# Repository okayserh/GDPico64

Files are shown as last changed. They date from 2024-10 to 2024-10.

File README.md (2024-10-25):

# GDPico64
Raspberry pico based graphics card to emulate an 80s EF9365 based graphics card to be used in conjunction with a modular 8 bit Z80 based computer system.

# Background
In the mid/late 80s, german public television broadcasted a series of 26 episodes of a stepwise introduction to microcomputer technology. It started with the usual stuff like binary logic, memory and the purpose of a central processing unit. Parallel to the explanations the series worked on building a modular 8 bit microcomputer, which was based on an 8 bit bus system. While the basic system used the Z80 CPU, it was possible to extend the system to an 68008 CPU board and with some tricks even to an 68020 CPU.
A full set of information and the required software is available on the following website (most of it is in german language):
www.ndr-nkc.de
In its modular setup it is conceptually very similar to the RC2014* project.

# Project
One cornerstone of the modular computer system was the graphics card named GDP64, where the 64 stands for 64kB of dedicated graphics memory, which offered 4 separate pages of 512x256 monochrome pixels (rather hi-res for that time!). The GDP64 was designed around the EF9365 graphics chip, which seems to have been one of the first graphics chips to offer a hardware implementation of graphics primitives like lines or characters. Since the chip has a MAME (www.mamedev.org) implementation, it seems to have found some use outside of this modular computer project but overall it is rather exotic. While the line drawing performance was quite impressive for its time with up to 1 Mio. Pixels/s, it lacked some features like scrolling or dedicated text modes.

This project uses the capabilities of the RP2040 to create a graphics output to support halfway modern displays (i.e. it produces an analog VGA signal where the current preferred resolution is 1920x1080@60Hz). Furthermore, the RP2040 provides a parallel interface to enable use of the GDPico64 in the same environment as the original.

As some GPIOs were free after having 8 Bit Color VGA output and the parallel bus, the board offers a PS/2 interface to connect a keyboard (this emulates the old KEY group). As an additional means of interfacing with the Z80 system, the Pico's stdio functionaliy (i.e. UART via USB) can also be used as keyboard input.

# Installation
The project assumes that the standard Pico SDK has been setup as documented in the official docs.

First the repository needs to be cloned into a separate directory:
```
git clone https://github.com/okayserh/GDPico64
```

Submodules are used to provide the FreeRTOS functions. These need to be cloned by:
```
git submodule update --init
```

For compiling the code a build directory needs to be setup with subsequent use of the CMake system
```
mkdir build
cd build
cmake ..
```

Building is than just
```
make
```

Installation on the Pico board follows the standard procedure. I.e. the .uf2 file created by the
build process is copied onto the drive presented by the Pico board.

# Usage
For the beginning, it is suggested to have a serial interface via USB. Once the initialization is completed, the monitor switches to "terminal" mode. In "terminal mode", the input received via the stdio serial interface is forwarded as key press to the Z80 system. Thus, the host keyboard can be used as input for the Z80 system. Pressing the ESC key of the host system, the software switches to "monitor mode". In monitor mode the following functions are available:

* X XModem receive
* S XModem send
* D Dump XModem buffer
* T Terminal mode
* I Dump IO buffer
* C Reset CAS bufptr
* R Reset Z80

The three functions XModem receive XModem send and Reset CAS bufptr are linked to the emulation of the original cassette interface (CAS). This interface uses a 6850 UART to convert data streams into recordable audio. The emulation uses a 4k buffer in RAM as a substitute for the cassette. The buffer can be filled from the host computer or the Z80. When the buffer has been filled via XModem, the pointer can be reset (via C) and the Z80 can read the data via the emulated 6850 interface. This allows the transmission of programs into the Z80 environment via XModem. For the opposite direction, the pointer into the buffer should be reset and the transmission from the Z80 be started. When the buffer has been filled, the XModem buffer can be send to the host computer via XModem.

With the "Dump XModel buffer" function, the current content of the cassette buffer can be displayed through the serial interface via USB.

As a debugging function, "Dump IO buffer" outputs all 256 IO registers that are used internally to emulate the different IO devices.

Finally, the "Reset Z80" function sends a reset signal via the Z80 bus and reinitializes the PIO handling the parallel bus.

# Remarks and TODOs
* As this is a weekend project, the code is not yet very nice from a software engineering or code quality perspective. Time allowing, the code quality will be improved and maybe also new features will be added.
* For many of the functions that are implemented in the code, I've been looking for sources to get some inspiration (DMA based LUT mapping, parallel port implementation). While there are some codes, I still think that the code may provide some insights into how those tasks could be done if these things should become part of another project.
* FreeRTOS was added in a later stage of the project as multiple things need to be monitored simultaneously and the initial simple scheduler became overly complex. Usage of FreeRTOS may not always be as it should be. But for the time being the code seems to work.
* The monitor is rather simple and only accessible from the USB serial interface. A possible extension would be to use the graphics output to provide a stand-alone monitor program that can be used to confgure the system
* Another extension would be to use the 8 bit color output to provide a color capable graphics interface. A simple concept would use the 4 pages as 4 bits encoding the color through the lookup table.
* Generally it is also conceivable to complete change the graphics interface into something more like an 80s homecomputer graphics.
* Addition of the floppy controller to enable the use of CP/M.

# Trademarks
    "RC2014" is a registered trademark of RFC2795 Ltd.
    Other names and brands may be claimed as the property of others.

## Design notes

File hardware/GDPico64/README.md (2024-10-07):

# GDPico64, Hardware
Raspberry pico based graphics card to emulate an 80s EF9365 based graphics card to be used in conjunction with a modular 8 bit Z80 based computer system.

# Layout and functions
Since my background is more on the software side, this is the first PCB I've developed. While it works in my setup, it may lack some features professional PCB designers or electrical engineers would add.

It uses 74245 chips to translate the Z80 bus signals into 3.3v signals that are compatible to the Pico GPIO pins. In order to save GPIOs on the Pico, the address and data part of the bus is multiplixed by using two 74245 chips. For outputting data signals to the Z80 bus, the 74245 chips are used as well. However, for the controlling the RESET and the WAIT signal an 5V inverter is used. While the 74245 worked for those signals as well in my breadboard development setup, there seems to be a risk that the 74245 is used out of spec in this setup when pull-up resitors drive the signals to 5V.

The VGA output is a simple resistor network inspired by the PICO VGA library.

Known shortcomings:
* No guarantee to do anything useful and leave other components to be used in conjuntion with this PCB undamaged! Use at your own risk!
* No protection against powering the Pico via the parallel bus and the USB port.
* As of now, only tested in a configuration where the whole system is powered through the USB port of the Pico.

# Release Notes
* Version 0.1:
  * Initial version

# Licensing

The hardware design itself, including schematic and PCB layout design files are licensed under the strongly-reciprocal variant of [CERN Open Hardware Licence version 2](license-cern_ohl_s_v2.txt).

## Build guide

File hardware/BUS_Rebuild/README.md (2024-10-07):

# BUS "Rebuild"
The BUS group was at the heart of the modular computer system. It provided a bus for 6 PCBs that usually included the CPU, some memory cards and some IO respectively Graphics cards.

Since the original PCBs are "unobtainium", I've spend an evening redesigning the original BUS backplane. I've made a few minor modifications to the original layout.

# Licensing

The hardware design itself, including schematic and PCB layout design files are licensed under the strongly-reciprocal variant of [CERN Open Hardware Licence version 2](license-cern_ohl_s_v2.txt).

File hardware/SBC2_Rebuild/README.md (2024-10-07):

# SBC2 "Rebuild"
The SBC2 was a card that included the Z80 CPU, 8k of EPROM and 4k of RAM on a single PCB. The EPROM was mapped to 0x0000-0x2000, while the RAM was located from 0x8000 to 0x9000. In order to have a complete system on the PCB, an oscillator circuit and the reset logic were also implemented on the board.

It is important to note, that this board was merely enough to use the basic program ("grundprogramm"), which could be considered a simple monitor with extensions to enter simple machine code programs and to write those programs to the cassette interface. For user interested in getting more from the modular concept, separate cards with distinct CPUs and Memories were offered. By using these cards, the system could be extended to 1MB of memory with some bank logic. In those configurations it was also possible to use the system together with CP/M.

Since my original SBC2 board was messed up with wrong solders, I decided to redraw the SBC2 with KiCad and order replacements from a PCB shop. The result can be found in this folder.

# Remarks:
The required memory types 2732 and 6116 are hard to come by today. With hindsight bias, it was not such a good idea to spend time to replicate this design. In my current working setup, the card is only populated with a single 6116, while the sockets are filled with wires to forward the address lines that are not provided to the bus in the original design. Also the reset logic is left unpopulated as the reset must be provided by the GDPico64 in order to have the parallel bus set up properly. Henc,e, in my working setup it is mostly used ad clock generator and holder for the Z80 CPU.
Another point which seems not quite up to date is the dimensioning of the pull-up resistors. Those are 1k resistors, which to me seem rather strong by current CMOS standards.
The logic for the clock generation works, but the signal is not very good. Using an off the shelve oscillator might have been a better option for the redesign.

# Licensing
The copyright of the original PCB design is by Rolf Dieter Klein, who was the mastermind behind the whole computer system
Copyright of PCB layouts seems to be a bit difficult. My understanding is that schematics cannot be copyrighted. However, individual layouts can be subject of copyright. In this work I've recreated the original layout in KiCad with some minimal modifications in routing. I don't know if this suffices to grant me the copyright on this design.
In case anyone feels that this design violates his/her copyright, please drop me a note and I'll take this part of the project offline.

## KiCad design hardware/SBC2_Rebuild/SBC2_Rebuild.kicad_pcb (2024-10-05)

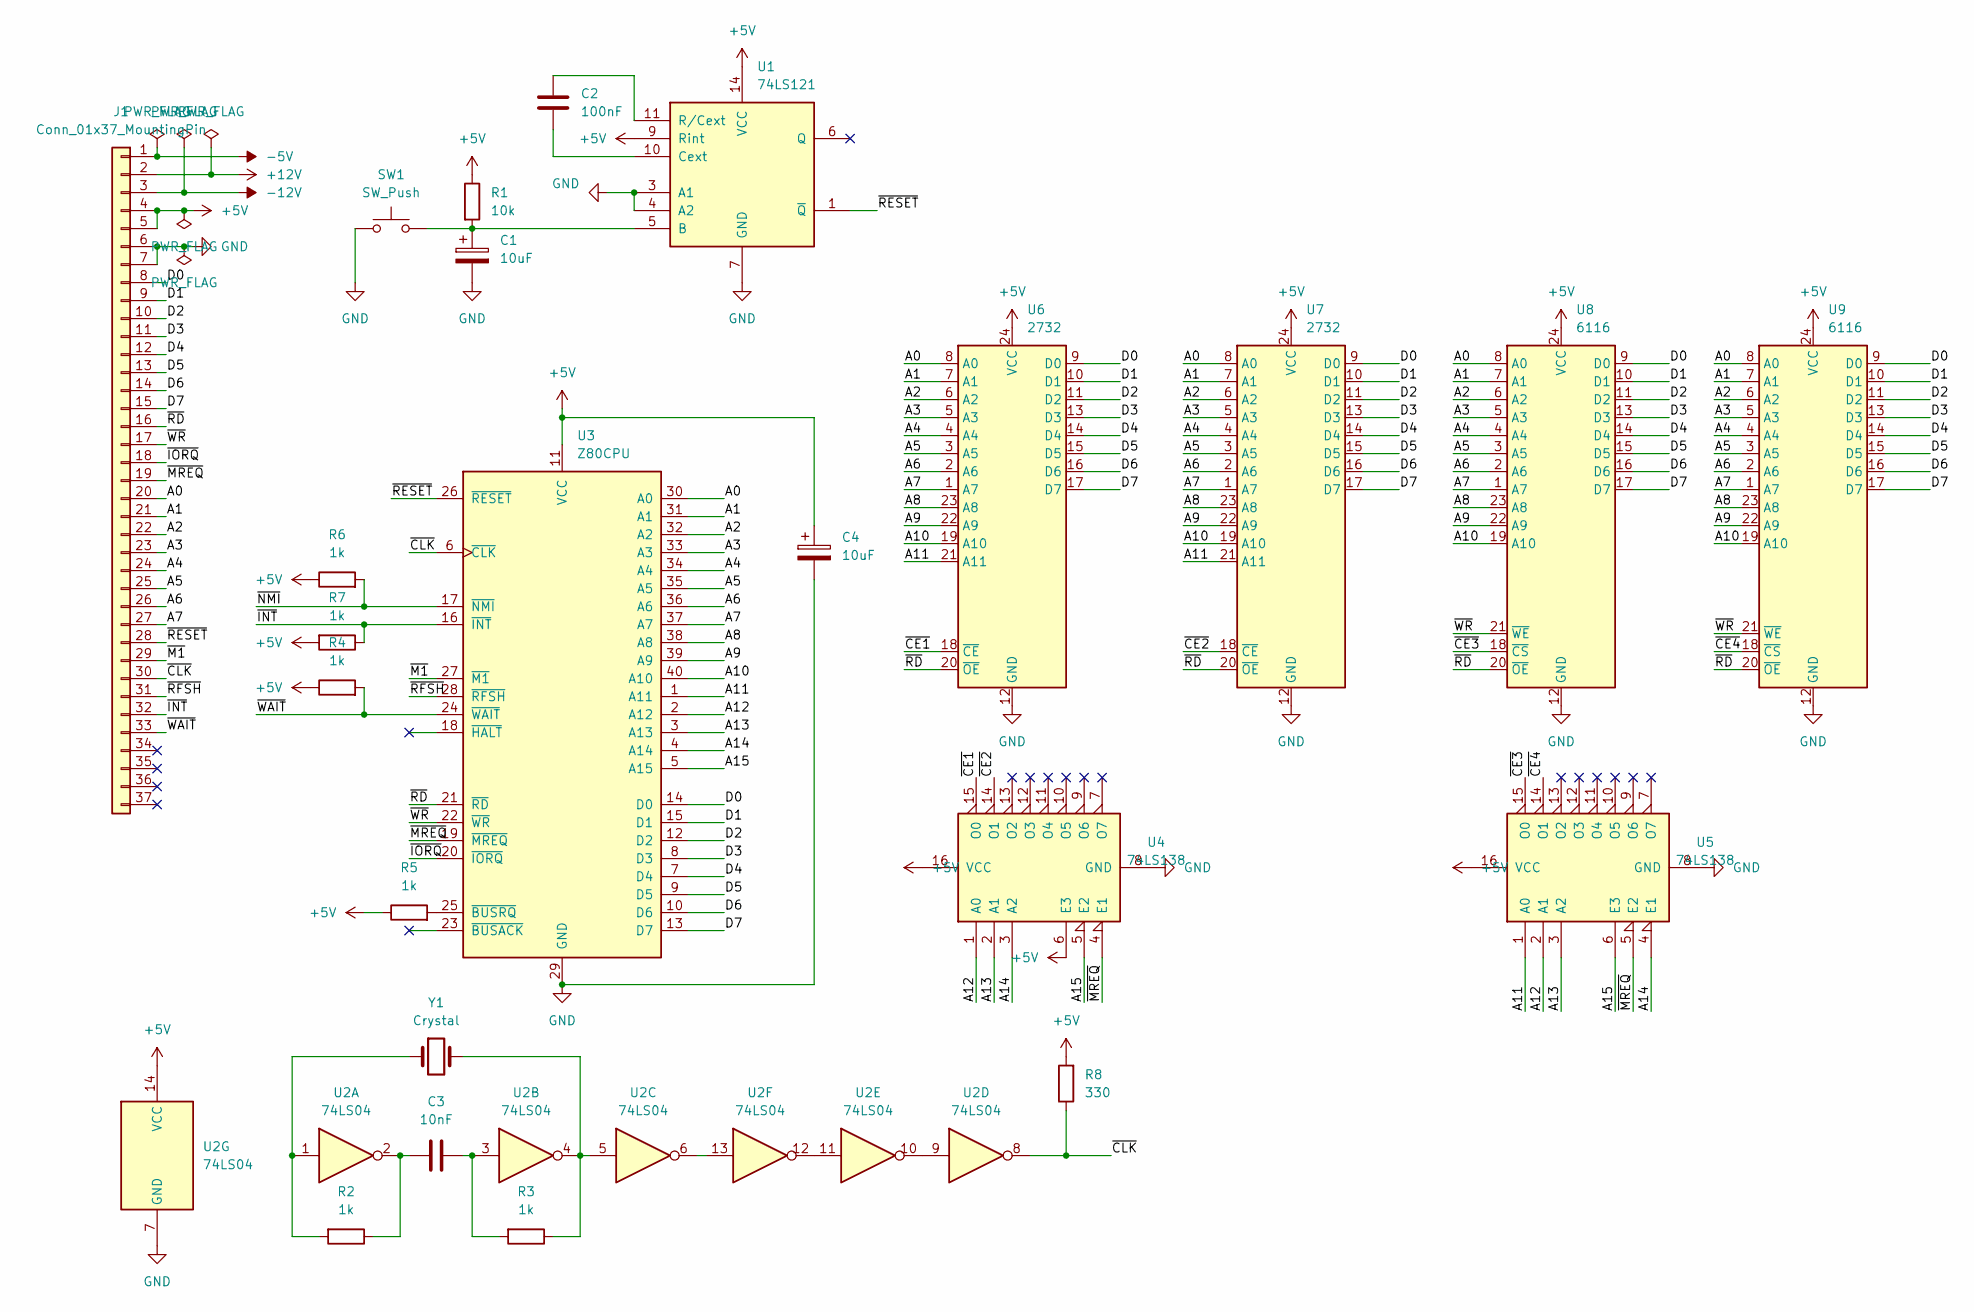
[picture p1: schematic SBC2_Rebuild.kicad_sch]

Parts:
C1, C4: 10uF; CP_Radial_Tantal_D4.5mm_P5.00mm
C2: 100nF; C_Disc_D5.0mm_W2.5mm_P5.00mm
C3: 10nF; C_Disc_D5.0mm_W2.5mm_P5.00mm
J1: Conn_01x37_MountingPin; PinHeader_1x37_P2.54mm_Horizontal
R1: 10k; R_Axial_DIN0207_L6.3mm_D2.5mm_P10.16mm_Horizontal
R2, R3, R4, R5, R6, R7: 1k; R_Axial_DIN0207_L6.3mm_D2.5mm_P10.16mm_Horizontal
R8: 330; R_Axial_DIN0207_L6.3mm_D2.5mm_P10.16mm_Horizontal
SW1: SW_Push; PinHeader_1x02_P2.54mm_Vertical
U1: 74LS121; DIP-14_W7.62mm_Socket
U2: 74LS04; DIP-14_W7.62mm_Socket
U3: Z80CPU; DIP-40_W15.24mm_Socket
U4, U5: 74LS138; DIP-16_W7.62mm_Socket
U6, U7: 2732; DIP-24_W15.24mm_Socket
U8, U9: 6116; DIP-24_W15.24mm_Socket
Y1: Crystal; Crystal_HC18-U_Vertical

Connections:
+5V: C4.1, J1.4, J1.5, R1.1, R4.1, R5.1, R6.1, R7.2, R8.2, U1.9 (Rint), U1.14 (VCC), U2.14 (VCC), U3.11 (VCC), U4.6 (E3), U4.16 (VCC), U5.16 (VCC), U6.24 (VCC), U7.24 (VCC), U8.24 (VCC), U9.24 (VCC)
+12V: J1.2
-5V: J1.1
-12V: J1.3
/A0: J1.20, U3.30 (A0), U6.8 (A0), U7.8 (A0), U8.8 (A0), U9.8 (A0)
/A1: J1.21, U3.31 (A1), U6.7 (A1), U7.7 (A1), U8.7 (A1), U9.7 (A1)
/A2: J1.22, U3.32 (A2), U6.6 (A2), U7.6 (A2), U8.6 (A2), U9.6 (A2)
/A3: J1.23, U3.33 (A3), U6.5 (A3), U7.5 (A3), U8.5 (A3), U9.5 (A3)
/A4: J1.24, U3.34 (A4), U6.4 (A4), U7.4 (A4), U8.4 (A4), U9.4 (A4)
/A5: J1.25, U3.35 (A5), U6.3 (A5), U7.3 (A5), U8.3 (A5), U9.3 (A5)
/A6: J1.26, U3.36 (A6), U6.2 (A6), U7.2 (A6), U8.2 (A6), U9.2 (A6)
/A7: J1.27, U3.37 (A7), U6.1 (A7), U7.1 (A7), U8.1 (A7), U9.1 (A7)
/A8: U3.38 (A8), U6.23 (A8), U7.23 (A8), U8.23 (A8), U9.23 (A8)
/A9: U3.39 (A9), U6.22 (A9), U7.22 (A9), U8.22 (A9), U9.22 (A9)
/A10: U3.40 (A10), U6.19 (A10), U7.19 (A10), U8.19 (A10), U9.19 (A10)
/A11: U3.1 (A11), U5.1 (A0), U6.21 (A11), U7.21 (A11)
/A12: U3.2 (A12), U4.1 (A0), U5.2 (A1)
/A13: U3.3 (A13), U4.2 (A1), U5.3 (A2)
/A14: U3.4 (A14), U4.3 (A2), U5.4 (E1)
/A15: U3.5 (A15), U4.5 (E2), U5.6 (E3)
/D0: J1.8, U3.14 (D0), U6.9 (D0), U7.9 (D0), U8.9 (D0), U9.9 (D0)
/D1: J1.9, U3.15 (D1), U6.10 (D1), U7.10 (D1), U8.10 (D1), U9.10 (D1)
/D2: J1.10, U3.12 (D2), U6.11 (D2), U7.11 (D2), U8.11 (D2), U9.11 (D2)
/D3: J1.11, U3.8 (D3), U6.13 (D3), U7.13 (D3), U8.13 (D3), U9.13 (D3)
/D4: J1.12, U3.7 (D4), U6.14 (D4), U7.14 (D4), U8.14 (D4), U9.14 (D4)
/D5: J1.13, U3.9 (D5), U6.15 (D5), U7.15 (D5), U8.15 (D5), U9.15 (D5)
/D6: J1.14, U3.10 (D6), U6.16 (D6), U7.16 (D6), U8.16 (D6), U9.16 (D6)
/D7: J1.15, U3.13 (D7), U6.17 (D7), U7.17 (D7), U8.17 (D7), U9.17 (D7)
/~CE1: U4.15 (O0), U6.18 (~CE)
/~CE2: U4.14 (O1), U7.18 (~CE)
/~CE3: U5.15 (O0), U8.18 (~CS)
/~CE4: U5.14 (O1), U9.18 (~CS)
/~CLK: J1.30, R8.1, U2.8, U3.6 (~CLK)
/~INT: J1.32, R7.1, U3.16 (~INT)
/~IORQ: J1.18, U3.20 (~IORQ)
/~M1: J1.29, U3.27 (~M1)
/~MREQ: J1.19, U3.19 (~MREQ), U4.4 (E1), U5.5 (E2)
/~NMI: R6.2, U3.17 (~NMI)
/~RD: J1.16, U3.21 (~RD), U6.20 (~OE), U7.20 (~OE), U8.20 (~OE), U9.20 (~OE)
/~RESET: J1.28, U1.1 (~Q), U3.26 (~RESET)
/~RFSH: J1.31, U3.28 (~RFSH)
/~WAIT: J1.33, R4.2, U3.24 (~WAIT)
/~WR: J1.17, U3.22 (~WR), U8.21 (~WE), U9.21 (~WE)
GND: C1.2, C4.2, J1.6, J1.7, SW1.1, U1.3 (A1), U1.4 (A2), U1.7 (GND), U2.7 (GND), U3.29 (GND), U4.8 (GND), U5.8 (GND), U6.12 (GND), U7.12 (GND), U8.12 (GND), U9.12 (GND)
unnamed: C1.1, R1.2, SW1.2, U1.5 (B)
unnamed: C2.1, U1.11 (R/Cext)
unnamed: C2.2, U1.10 (Cext)
unnamed: C3.1, R3.2, U2.3
unnamed: C3.2, R2.1, U2.2
unnamed: R2.2, U2.1, Y1.1
unnamed: R3.1, U2.4, U2.5, Y1.2
unnamed: R5.2, U3.25 (~BUSRQ)
unnamed: U2.9, U2.10
unnamed: U2.11, U2.12
unnamed: U2.6, U2.13

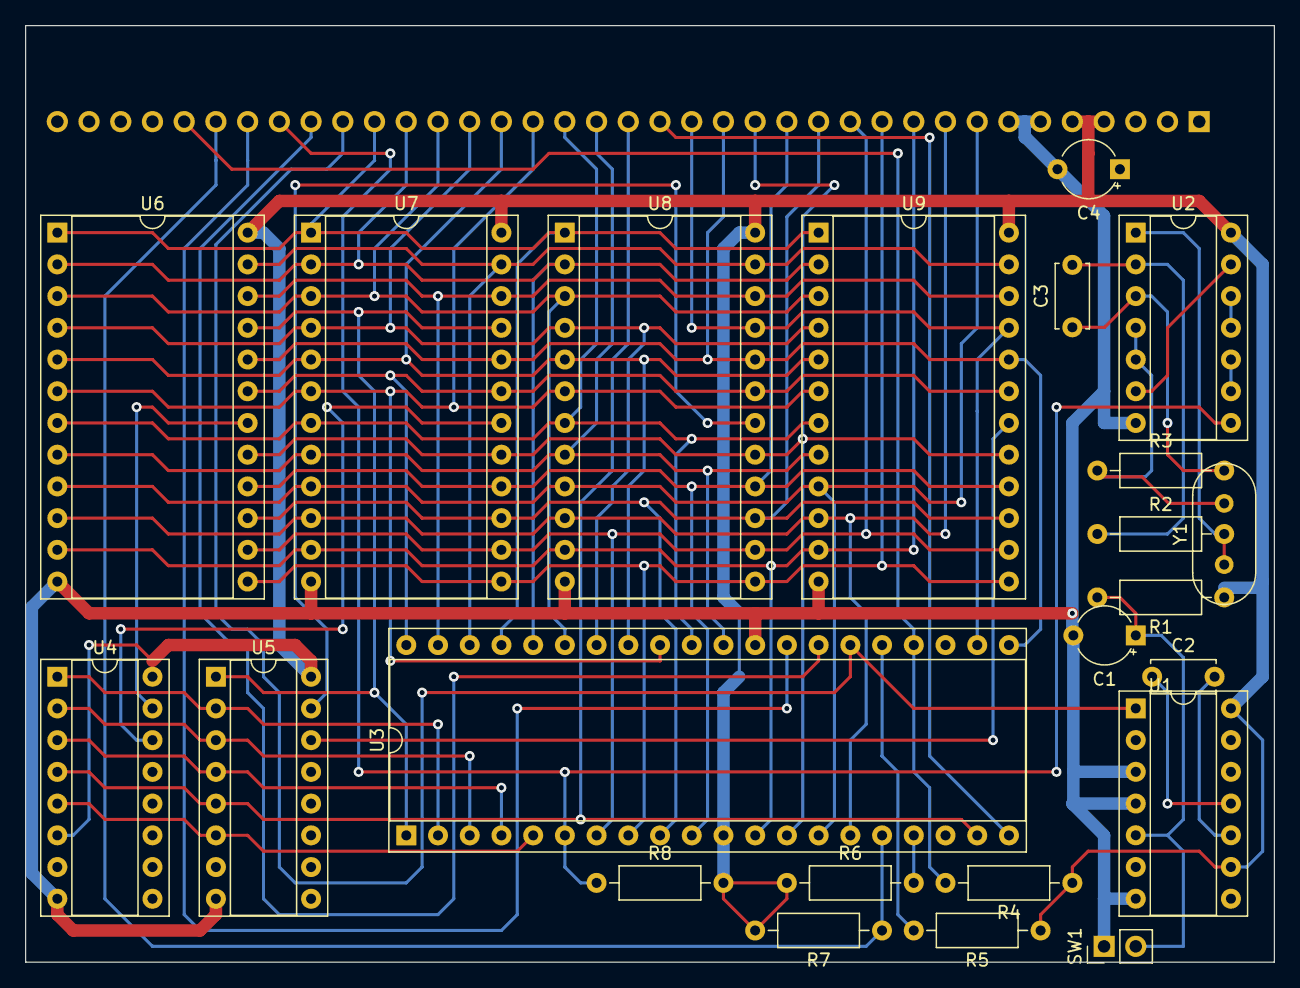
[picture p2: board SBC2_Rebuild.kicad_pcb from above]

Board: 2 copper layers, 100.0 x 75.0 mm, 24 parts (1 on the bottom side), 52 nets.

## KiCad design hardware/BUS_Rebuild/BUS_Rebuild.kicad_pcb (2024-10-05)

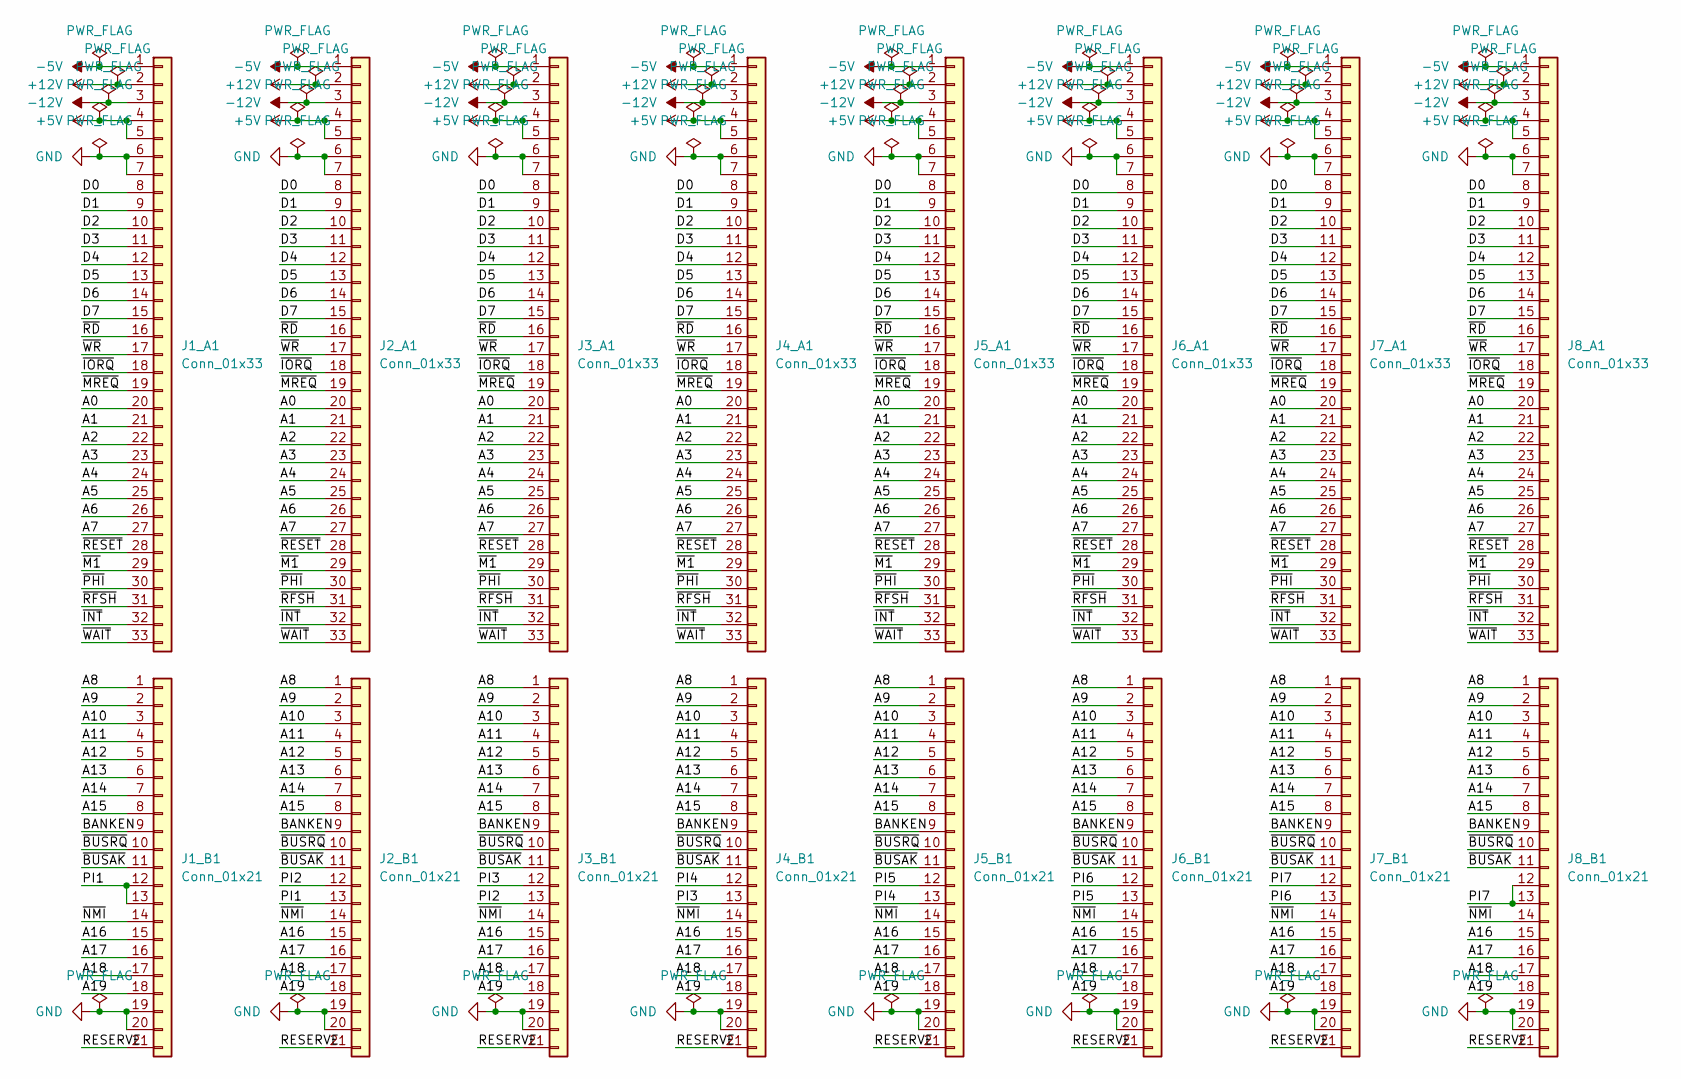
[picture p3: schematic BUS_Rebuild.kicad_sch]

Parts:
J1_A1, J2_A1, J3_A1, J4_A1, J5_A1, J6_A1, J7_A1, J8_A1: Conn_01x33; PinSocket_1x33_P2.54mm_Vertical
J1_B1, J2_B1, J3_B1, J4_B1, J5_B1, J6_B1, J7_B1, J8_B1: Conn_01x21; PinSocket_1x21_P2.54mm_Vertical

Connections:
+5V: J1_A1.4, J1_A1.5, J2_A1.4, J2_A1.5, J3_A1.4, J3_A1.5, J4_A1.4, J4_A1.5, J5_A1.4, J5_A1.5, J6_A1.4, J6_A1.5, J7_A1.4, J7_A1.5, J8_A1.4, J8_A1.5
+12V: J1_A1.2, J2_A1.2, J3_A1.2, J4_A1.2, J5_A1.2, J6_A1.2, J7_A1.2, J8_A1.2
-5V: J1_A1.1, J2_A1.1, J3_A1.1, J4_A1.1, J5_A1.1, J6_A1.1, J7_A1.1, J8_A1.1
-12V: J1_A1.3, J2_A1.3, J3_A1.3, J4_A1.3, J5_A1.3, J6_A1.3, J7_A1.3, J8_A1.3
/A0: J1_A1.20, J2_A1.20, J3_A1.20, J4_A1.20, J5_A1.20, J6_A1.20, J7_A1.20, J8_A1.20
/A1: J1_A1.21, J2_A1.21, J3_A1.21, J4_A1.21, J5_A1.21, J6_A1.21, J7_A1.21, J8_A1.21
/A2: J1_A1.22, J2_A1.22, J3_A1.22, J4_A1.22, J5_A1.22, J6_A1.22, J7_A1.22, J8_A1.22
/A3: J1_A1.23, J2_A1.23, J3_A1.23, J4_A1.23, J5_A1.23, J6_A1.23, J7_A1.23, J8_A1.23
/A4: J1_A1.24, J2_A1.24, J3_A1.24, J4_A1.24, J5_A1.24, J6_A1.24, J7_A1.24, J8_A1.24
/A5: J1_A1.25, J2_A1.25, J3_A1.25, J4_A1.25, J5_A1.25, J6_A1.25, J7_A1.25, J8_A1.25
/A6: J1_A1.26, J2_A1.26, J3_A1.26, J4_A1.26, J5_A1.26, J6_A1.26, J7_A1.26, J8_A1.26
/A7: J1_A1.27, J2_A1.27, J3_A1.27, J4_A1.27, J5_A1.27, J6_A1.27, J7_A1.27, J8_A1.27
/A8: J1_B1.1, J2_B1.1, J3_B1.1, J4_B1.1, J5_B1.1, J6_B1.1, J7_B1.1, J8_B1.1
/A9: J1_B1.2, J2_B1.2, J3_B1.2, J4_B1.2, J5_B1.2, J6_B1.2, J7_B1.2, J8_B1.2
/A10: J1_B1.3, J2_B1.3, J3_B1.3, J4_B1.3, J5_B1.3, J6_B1.3, J7_B1.3, J8_B1.3
/A11: J1_B1.4, J2_B1.4, J3_B1.4, J4_B1.4, J5_B1.4, J6_B1.4, J7_B1.4, J8_B1.4
/A12: J1_B1.5, J2_B1.5, J3_B1.5, J4_B1.5, J5_B1.5, J6_B1.5, J7_B1.5, J8_B1.5
/A13: J1_B1.6, J2_B1.6, J3_B1.6, J4_B1.6, J5_B1.6, J6_B1.6, J7_B1.6, J8_B1.6
/A14: J1_B1.7, J2_B1.7, J3_B1.7, J4_B1.7, J5_B1.7, J6_B1.7, J7_B1.7, J8_B1.7
/A15: J1_B1.8, J2_B1.8, J3_B1.8, J4_B1.8, J5_B1.8, J6_B1.8, J7_B1.8, J8_B1.8
/A16: J1_B1.15, J2_B1.15, J3_B1.15, J4_B1.15, J5_B1.15, J6_B1.15, J7_B1.15, J8_B1.15
/A17: J1_B1.16, J2_B1.16, J3_B1.16, J4_B1.16, J5_B1.16, J6_B1.16, J7_B1.16, J8_B1.16
/A18: J1_B1.17, J2_B1.17, J3_B1.17, J4_B1.17, J5_B1.17, J6_B1.17, J7_B1.17, J8_B1.17
/A19: J1_B1.18, J2_B1.18, J3_B1.18, J4_B1.18, J5_B1.18, J6_B1.18, J7_B1.18, J8_B1.18
/BANKEN: J1_B1.9, J2_B1.9, J3_B1.9, J4_B1.9, J5_B1.9, J6_B1.9, J7_B1.9, J8_B1.9
/D0: J1_A1.8, J2_A1.8, J3_A1.8, J4_A1.8, J5_A1.8, J6_A1.8, J7_A1.8, J8_A1.8
/D1: J1_A1.9, J2_A1.9, J3_A1.9, J4_A1.9, J5_A1.9, J6_A1.9, J7_A1.9, J8_A1.9
/D2: J1_A1.10, J2_A1.10, J3_A1.10, J4_A1.10, J5_A1.10, J6_A1.10, J7_A1.10, J8_A1.10
/D3: J1_A1.11, J2_A1.11, J3_A1.11, J4_A1.11, J5_A1.11, J6_A1.11, J7_A1.11, J8_A1.11
/D4: J1_A1.12, J2_A1.12, J3_A1.12, J4_A1.12, J5_A1.12, J6_A1.12, J7_A1.12, J8_A1.12
/D5: J1_A1.13, J2_A1.13, J3_A1.13, J4_A1.13, J5_A1.13, J6_A1.13, J7_A1.13, J8_A1.13
/D6: J1_A1.14, J2_A1.14, J3_A1.14, J4_A1.14, J5_A1.14, J6_A1.14, J7_A1.14, J8_A1.14
/D7: J1_A1.15, J2_A1.15, J3_A1.15, J4_A1.15, J5_A1.15, J6_A1.15, J7_A1.15, J8_A1.15
/PI1: J1_B1.12, J1_B1.13, J2_B1.13
/PI2: J2_B1.12, J3_B1.13
/PI3: J3_B1.12, J4_B1.13
/PI4: J4_B1.12, J5_B1.13
/PI5: J5_B1.12, J6_B1.13
/PI6: J6_B1.12, J7_B1.13
/PI7: J7_B1.12, J8_B1.12, J8_B1.13
/RESERVE: J1_B1.21, J2_B1.21, J3_B1.21, J4_B1.21, J5_B1.21, J6_B1.21, J7_B1.21, J8_B1.21
/~BUSAK: J1_B1.11, J2_B1.11, J3_B1.11, J4_B1.11, J5_B1.11, J6_B1.11, J7_B1.11, J8_B1.11
/~BUSRQ: J1_B1.10, J2_B1.10, J3_B1.10, J4_B1.10, J5_B1.10, J6_B1.10, J7_B1.10, J8_B1.10
/~INT: J1_A1.32, J2_A1.32, J3_A1.32, J4_A1.32, J5_A1.32, J6_A1.32, J7_A1.32, J8_A1.32
/~IORQ: J1_A1.18, J2_A1.18, J3_A1.18, J4_A1.18, J5_A1.18, J6_A1.18, J7_A1.18, J8_A1.18
/~M1: J1_A1.29, J2_A1.29, J3_A1.29, J4_A1.29, J5_A1.29, J6_A1.29, J7_A1.29, J8_A1.29
/~MREQ: J1_A1.19, J2_A1.19, J3_A1.19, J4_A1.19, J5_A1.19, J6_A1.19, J7_A1.19, J8_A1.19
/~NMI: J1_B1.14, J2_B1.14, J3_B1.14, J4_B1.14, J5_B1.14, J6_B1.14, J7_B1.14, J8_B1.14
/~PHI: J1_A1.30, J2_A1.30, J3_A1.30, J4_A1.30, J5_A1.30, J6_A1.30, J7_A1.30, J8_A1.30
/~RD: J1_A1.16, J2_A1.16, J3_A1.16, J4_A1.16, J5_A1.16, J6_A1.16, J7_A1.16, J8_A1.16
/~RESET: J1_A1.28, J2_A1.28, J3_A1.28, J4_A1.28, J5_A1.28, J6_A1.28, J7_A1.28, J8_A1.28
/~RFSH: J1_A1.31, J2_A1.31, J3_A1.31, J4_A1.31, J5_A1.31, J6_A1.31, J7_A1.31, J8_A1.31
/~WAIT: J1_A1.33, J2_A1.33, J3_A1.33, J4_A1.33, J5_A1.33, J6_A1.33, J7_A1.33, J8_A1.33
/~WR: J1_A1.17, J2_A1.17, J3_A1.17, J4_A1.17, J5_A1.17, J6_A1.17, J7_A1.17, J8_A1.17
GND: J1_A1.6, J1_A1.7, J1_B1.19, J1_B1.20, J2_A1.6, J2_A1.7, J2_B1.19, J2_B1.20, J3_A1.6, J3_A1.7, J3_B1.19, J3_B1.20, J4_A1.6, J4_A1.7, J4_B1.19, J4_B1.20, J5_A1.6, J5_A1.7, J5_B1.19, J5_B1.20, J6_A1.6, J6_A1.7, J6_B1.19, J6_B1.20, J7_A1.6, J7_A1.7, J7_B1.19, J7_B1.20, J8_A1.6, J8_A1.7, J8_B1.19, J8_B1.20

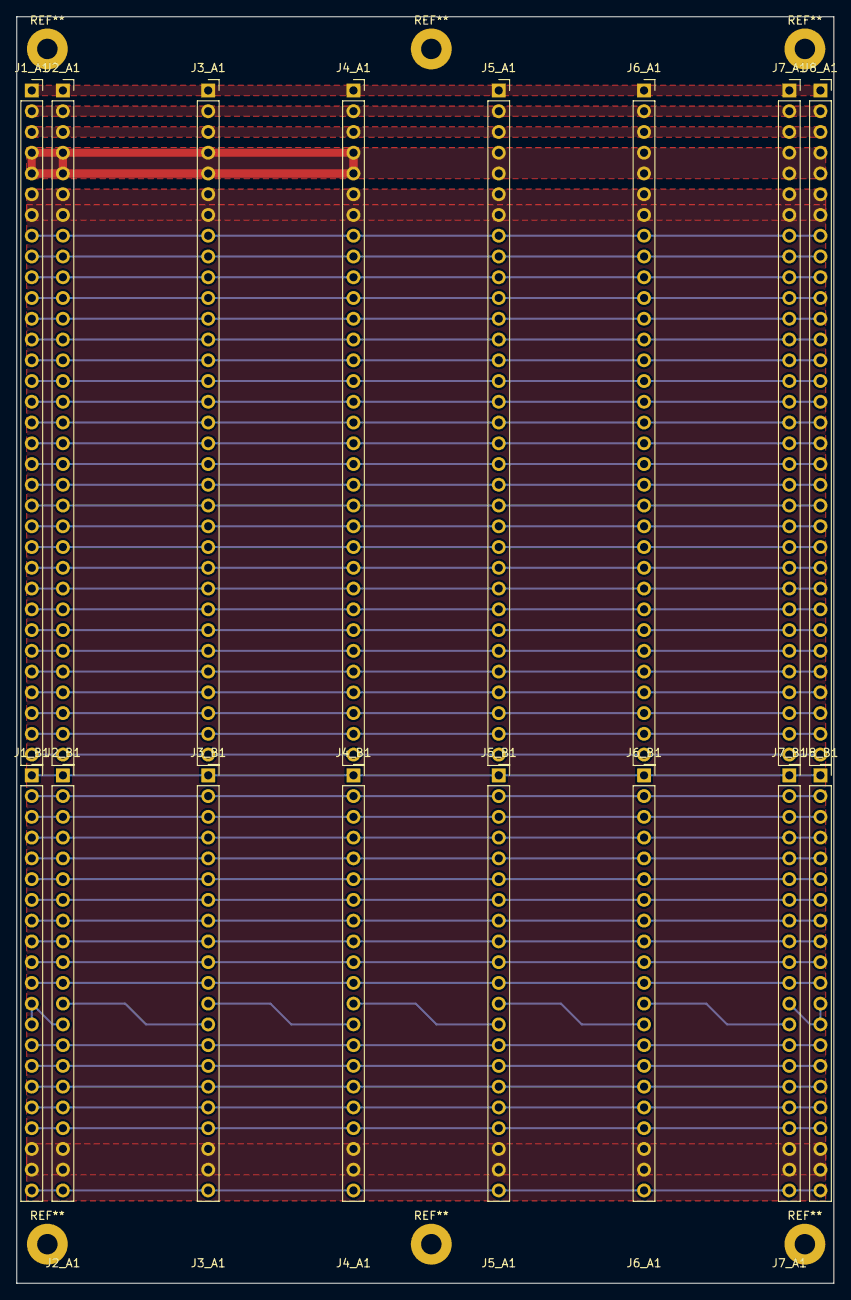
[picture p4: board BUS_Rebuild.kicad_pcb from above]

Board: 2 copper layers, 100.0 x 155.0 mm, 16 parts (0 on the bottom side), 55 nets.

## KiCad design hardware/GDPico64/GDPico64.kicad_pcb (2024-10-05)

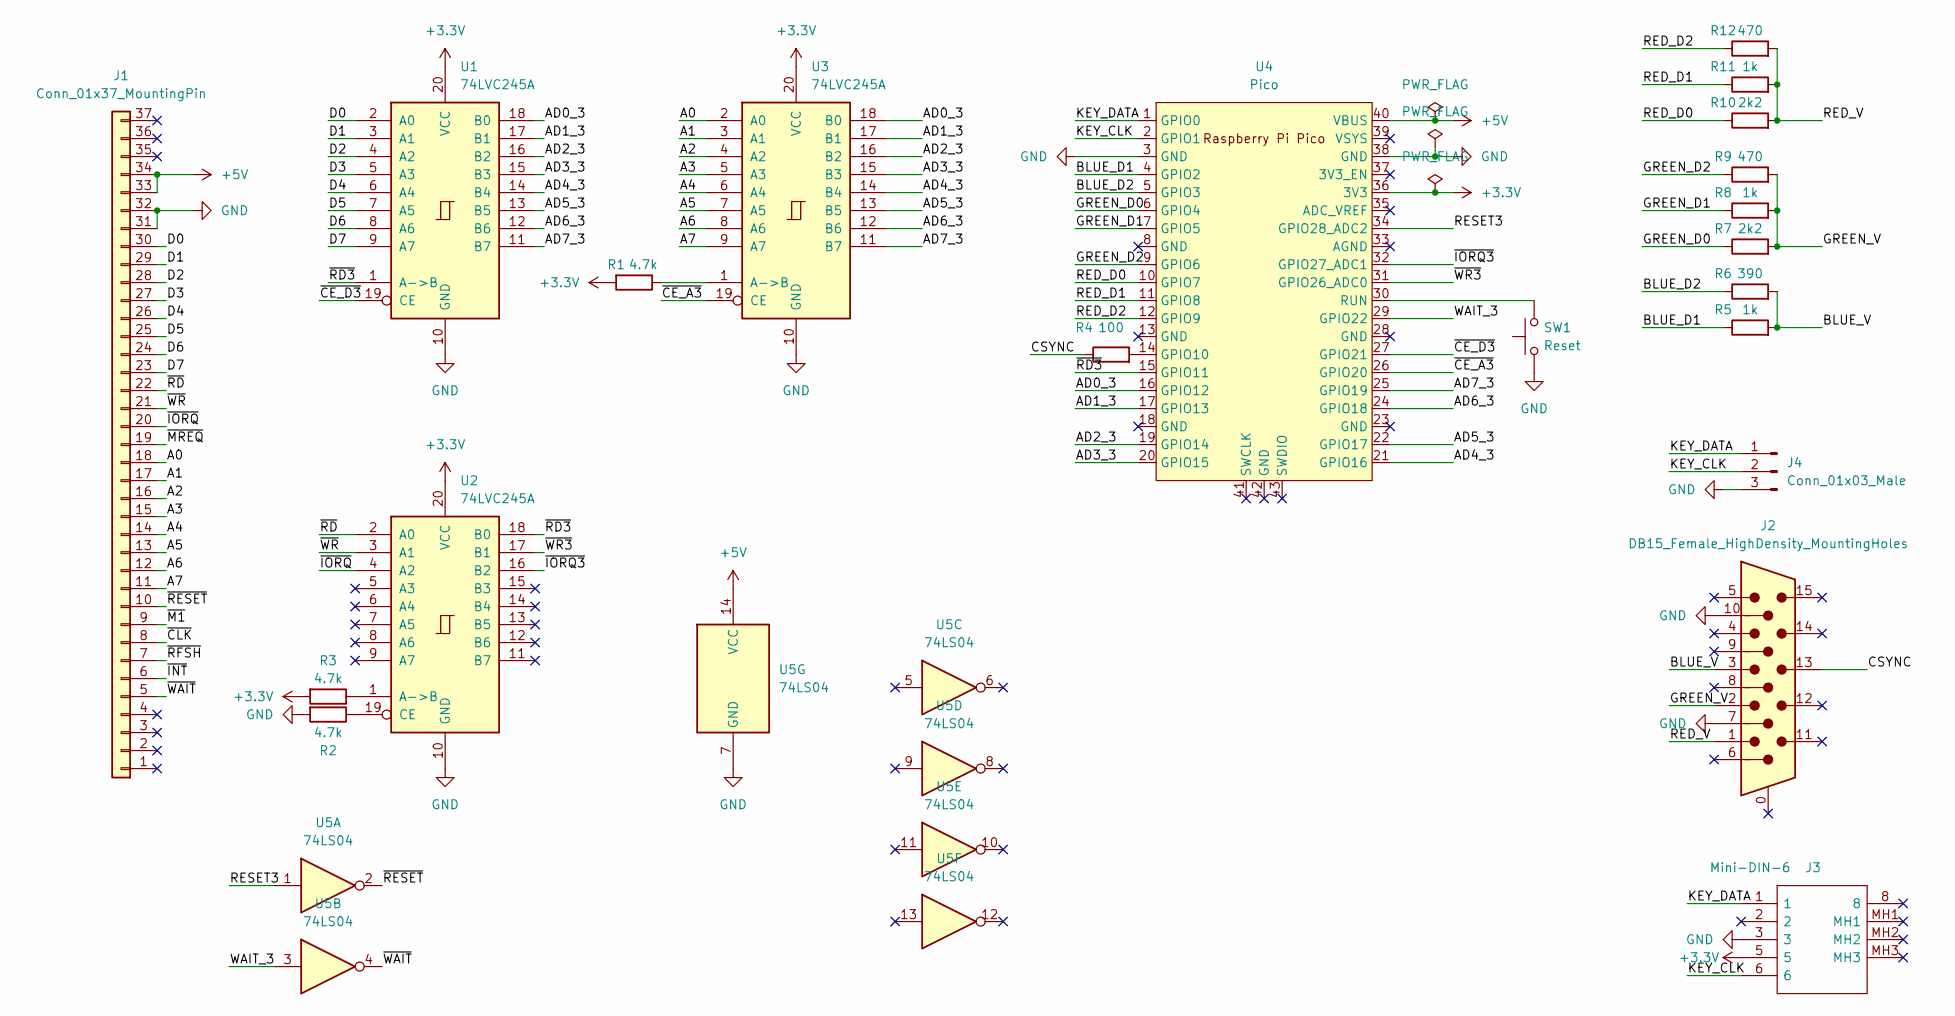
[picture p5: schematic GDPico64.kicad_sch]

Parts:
J1: Conn_01x37_MountingPin; PinHeader_1x37_P2.54mm_Horizontal
J2: DB15_Female_HighDensity_MountingHoles; DSUB-15-HD_Female_Horizontal_P2.29x1.98mm_EdgePinOffset8.35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
J3: Mini-DIN-6; KMDGX6SBS; Manufacturer_Part_Number KMDGX-6S-BS; Mouser Part Number 806-KMDGX-6S-BS
J4: Conn_01x03_Male; PinHeader_1x03_P2.54mm_Horizontal
R1, R2, R3: 4.7k; R_Axial_DIN0207_L6.3mm_D2.5mm_P10.16mm_Horizontal
R4: 100; R_Axial_DIN0207_L6.3mm_D2.5mm_P10.16mm_Horizontal
R5, R8, R11: 1k; R_Axial_DIN0207_L6.3mm_D2.5mm_P10.16mm_Horizontal
R6: 390; R_Axial_DIN0207_L6.3mm_D2.5mm_P10.16mm_Horizontal
R7, R10: 2k2; R_Axial_DIN0207_L6.3mm_D2.5mm_P10.16mm_Horizontal
R9, R12: 470; R_Axial_DIN0207_L6.3mm_D2.5mm_P10.16mm_Horizontal
SW1: Reset; SW_Tactile_SPST_Angled_PTS645Vx58-2LFS
U1, U2, U3: 74LVC245A; DIP-20_W7.62mm
U4: Pico; RPi_Pico_SMD_TH
U5: 74LS04; DIP-14_W7.62mm

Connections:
+3V3: J3.5, R1.2, R3.2, U1.20 (VCC), U2.20 (VCC), U3.20 (VCC), U4.36 (3V3)
+5V: J1.33, J1.34, U4.40 (VBUS), U5.14 (VCC)
/A0: J1.18, U3.2 (A0)
/A1: J1.17, U3.3 (A1)
/A2: J1.16, U3.4 (A2)
/A3: J1.15, U3.5 (A3)
/A4: J1.14, U3.6 (A4)
/A5: J1.13, U3.7 (A5)
/A6: J1.12, U3.8 (A6)
/A7: J1.11, U3.9 (A7)
/AD0_3: U1.18 (B0), U3.18 (B0), U4.16 (GPIO12)
/AD1_3: U1.17 (B1), U3.17 (B1), U4.17 (GPIO13)
/AD2_3: U1.16 (B2), U3.16 (B2), U4.19 (GPIO14)
/AD3_3: U1.15 (B3), U3.15 (B3), U4.20 (GPIO15)
/AD4_3: U1.14 (B4), U3.14 (B4), U4.21 (GPIO16)
/AD5_3: U1.13 (B5), U3.13 (B5), U4.22 (GPIO17)
/AD6_3: U1.12 (B6), U3.12 (B6), U4.24 (GPIO18)
/AD7_3: U1.11 (B7), U3.11 (B7), U4.25 (GPIO19)
/BLUE_D1: R5.1, U4.4 (GPIO2)
/BLUE_D2: R6.1, U4.5 (GPIO3)
/BLUE_V: J2.3, R5.2, R6.2
/CSYNC: J2.13, R4.1
/D0: J1.30, U1.2 (A0)
/D1: J1.29, U1.3 (A1)
/D2: J1.28, U1.4 (A2)
/D3: J1.27, U1.5 (A3)
/D4: J1.26, U1.6 (A4)
/D5: J1.25, U1.7 (A5)
/D6: J1.24, U1.8 (A6)
/D7: J1.23, U1.9 (A7)
/GREEN_D0: R7.1, U4.6 (GPIO4)
/GREEN_D1: R8.1, U4.7 (GPIO5)
/GREEN_D2: R9.1, U4.9 (GPIO6)
/GREEN_V: J2.2, R7.2, R8.2, R9.2
/KEY_CLK: J3.6, J4.2, U4.2 (GPIO1)
/KEY_DATA: J3.1, J4.1, U4.1 (GPIO0)
/RED_D0: R10.1, U4.10 (GPIO7)
/RED_D1: R11.1, U4.11 (GPIO8)
/RED_D2: R12.1, U4.12 (GPIO9)
/RED_V: J2.1, R10.2, R11.2, R12.2
/RESET3: U4.34 (GPIO28_ADC2), U5.1
/WAIT_3: U4.29 (GPIO22), U5.3
/~CE_A3: U3.19 (CE), U4.26 (GPIO20)
/~CE_D3: U1.19 (CE), U4.27 (GPIO21)
/~CLK: J1.8
/~INT: J1.6
/~IORQ3: U2.16 (B2), U4.32 (GPIO27_ADC1)
/~IORQ: J1.20, U2.4 (A2)
/~M1: J1.9
/~MREQ: J1.19
/~RD3: U1.1 (A->B), U2.18 (B0), U4.15 (GPIO11)
/~RD: J1.22, U2.2 (A0)
/~RESET: J1.10, U5.2
/~RFSH: J1.7
/~WAIT: J1.5, U5.4
/~WR3: U2.17 (B1), U4.31 (GPIO26_ADC0)
/~WR: J1.21, U2.3 (A1)
GND: J1.31, J1.32, J2.7, J2.10, J3.3, J4.3, R2.2, SW1.1, U1.10 (GND), U2.10 (GND), U3.10 (GND), U4.3 (GND), U4.38 (GND), U5.7 (GND)
unnamed: R1.1, U3.1 (A->B)
unnamed: R2.1, U2.19 (CE)
unnamed: R3.1, U2.1 (A->B)
unnamed: SW1.2, U4.30 (RUN)
unnamed: R4.2, U4.14 (GPIO10)

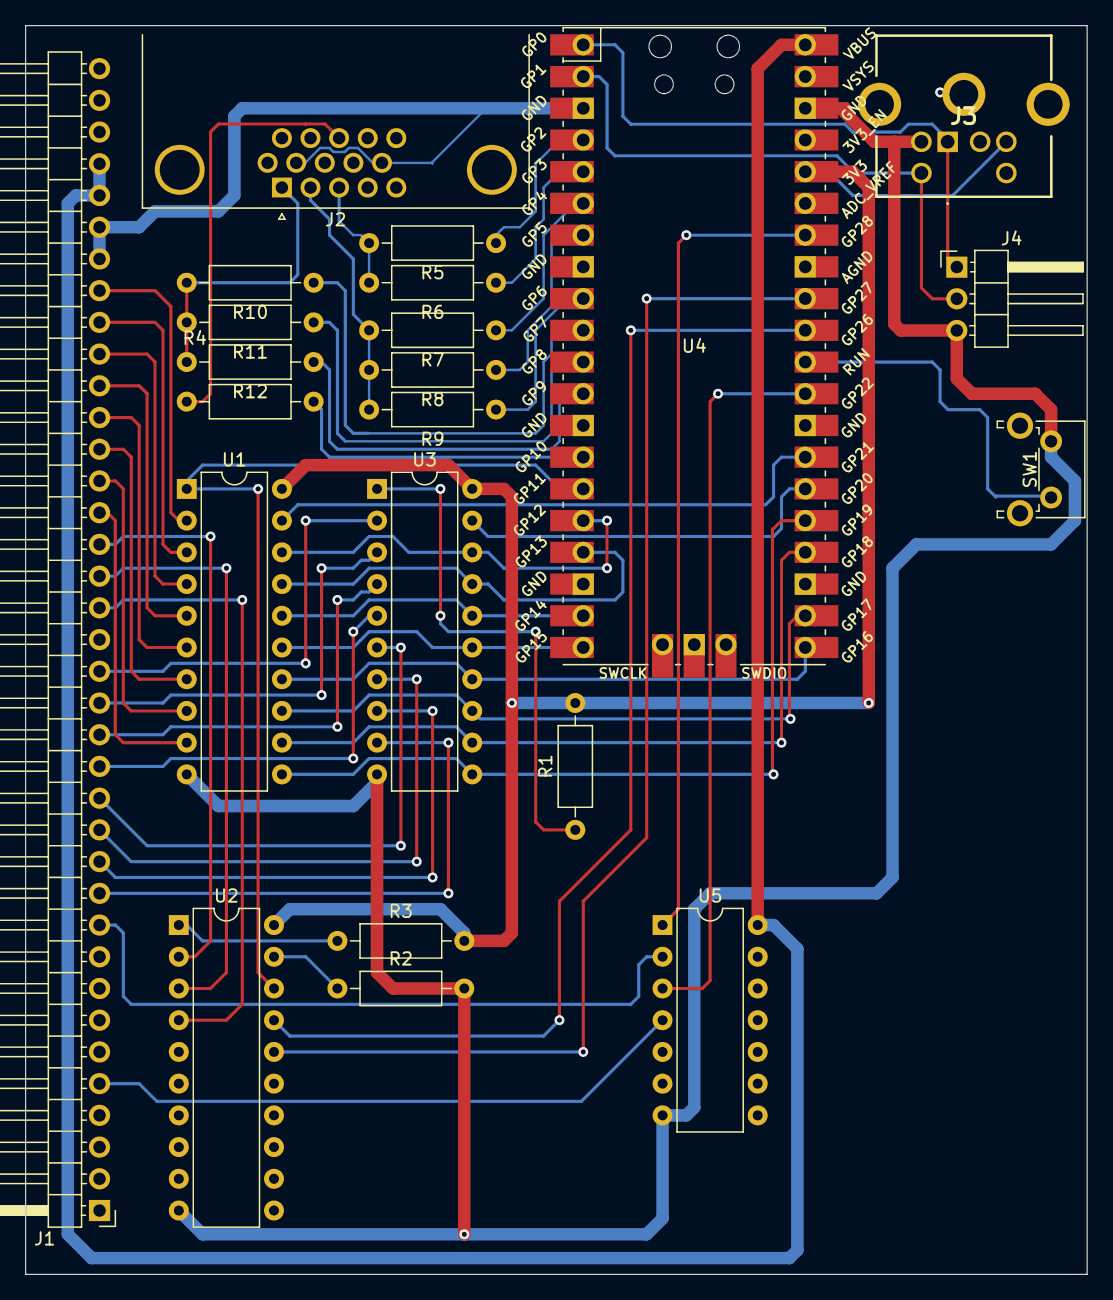
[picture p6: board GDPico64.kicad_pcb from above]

Board: 2 copper layers, 85.0 x 100.0 mm, 22 parts (0 on the bottom side), 58 nets.

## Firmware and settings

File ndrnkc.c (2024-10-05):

/**
 * ndrnkc.c
 *
 * Main program file. Calls device initialization functions
 * and sets up the main loop, which is a small monitor program
 *
 * Copyright (C) 2024  Oliver Kayser-Herold
 *
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
 * SPDX-License-Identifier: GPL-2.0-or-later
 */

// FreeRTOS
#include <FreeRTOS.h>
#include <task.h>
#include <queue.h>

#include "pico/stdlib.h"
#include "pico/multicore.h"
#include "hardware/pio.h"
#include "hardware/interp.h"
#include "hardware/dma.h"
#include "hardware/structs/sio.h"
#include "gdp.h"
#include "ps2key.h"
#include "cas.h"
#include "key.h"
#include "xmodem_pico.h"
#include "par_bus.h"
#include "stdio_dev.h"
#include "gpio_def.h"
#include <stdio.h>
#include <string.h>


uint8_t z80_io_buf[256];

typedef struct iodev_list_s
{
  QueueHandle_t queue;
  uint32_t (*iodev_funct)(uint8_t reg, uint8_t data);
} iodev_list;

iodev_list simdev[16];

// Free RTOS Stuff
TaskHandle_t monitor_task_handle = NULL;

// Defined in sim1.c
extern void z80_emulator (void);

/****************************************************************************
 * Name: ser_putc
 *
 * Description:
 *   Initial function for the simulation of the serial card of
 *   the modular computer.
 *
 * Input Parameters:
 *   reg    - The register that is addresses
 *   data   - Data to be output to the "serial port"
 *
 * Returned Value:
 *   Returns 0 when everything worked as expected
 *
 ****************************************************************************/

uint32_t ser_putc (uint8_t reg, uint8_t data)
{
  if (reg == 0xF0)
    // Output character
    xQueueSend (stdio_dev.output_queue, &data, pdMS_TO_TICKS (1));
  change_io_reg (0xF1, 0, 0x10);

  // Indicate not busy anymore
  return (0);
}

/****************************************************************************
 * Name: fifo_irq_handler
 *
 * Description:
 *   Interrupt handler for the FIFO that handles
 *   communication between Core 1 (Parbus) and
 *   Core 0 (Device implementation)
 *
 * Input Parameters:
 *   None
 *
 * Returned Value:
 *   None
 *
 ****************************************************************************/

void __not_in_flash_func(fifo_irq_handler)(void)
{
  // Notify fifo input task that information is pending in FIFO
  BaseType_t xHigherPriorityTaskWoken = pdFALSE;

  // Note: If the FIFO is not emptied, the interrupt will
  // directly be activated again when the function leaves.
  // This will lead to an endless loop :-/
  uint32_t fifo_rd;
  uint8_t dev;
  while (sio_hw->fifo_st & 0x1)
    {
      fifo_rd = sio_hw->fifo_rd;
      dev = (fifo_rd >> 12) & 0xF;

      if (simdev[dev].queue != NULL)
	xQueueSendFromISR (simdev[dev].queue,
			   &fifo_rd,
			   &xHigherPriorityTaskWoken);
    }

  // If error flags persist, clear them
  if (sio_hw->fifo_st & (0x8 + 0x4))
    sio_hw->fifo_st = 0;

  portYIELD_FROM_ISR (xHigherPriorityTaskWoken);
}

/****************************************************************************
 * Name: dump_mem_area
 *
 * Description:
 *   Prints the virtual IO space to stdio.
 *
 * Input Parameters:
 *   None
 *
 * Returned Value:
 *   None
 *
 ****************************************************************************/

void dump_mem_area ()
{
  printf ("IO\n");
  memcpy (z80_io_buf, z80_mem, 256);
  for (unsigned int i = 0; i < 256; ++i)
    {
      if ((i % 16) == 0)
	printf ("\n%02x: ", i);
      printf ("%02x ", z80_io_buf[i]);
    }

  printf ("\n\n");
}

/****************************************************************************
 * Name: reset_z80
 *
 * Description:
 *   Sends a reset signal on the Z80 bus.
 *
 * Input Parameters:
 *   None
 *
 * Returned Value:
 *   None
 *
 ****************************************************************************/

void reset_z80 ()
{
  PIO pio = pio0;

  // Start PIOs
  pio_sm_set_enabled(pio, 0, false);
  pio_sm_set_enabled(pio, 1, false);

  gpio_put (RESET, true);
  write_io_reg (0xF1, 0);

  pio_sm_restart(pio, 0);
  pio_sm_restart(pio, 1);

  pio_sm_set_enabled(pio, 0, true);
  pio_sm_set_enabled(pio, 1, true);

  vTaskDelay (1);
  gpio_put (RESET, false);
}

/****************************************************************************
 * Name: task_monitor
 *
 * Description:
 *   Calls the device initializations in the following sequence
 *   - Pico Stdio device
 *   - PS/2 Keyboard interface
 *   - CAS group (cassette interface)
 *   - GDP (graphics card based on EF9365)
 *   - Initialize parallel bus
 *   - Start second core (used solely for handling IO requests on the
 *     parallel bus)
 *   - Reset Z80
 *   After initialization it executes the main event loop for handling the monitor 
 *   that allows controlling the IO emulation via pico stdio.
 *
 * Input Parameters:
 *   unused_arg    - Provided by task initialization, currently unused
 *
 * Returned Value:
 *   None
 *
 ****************************************************************************/

void task_monitor(void* unused_arg) {
  // Initialize GPIO Pin for reset
  gpio_init (RESET);
  gpio_set_dir(RESET, GPIO_OUT);
  gpio_pull_up (RESET);  // ~RESET
  gpio_put (RESET, false);

  // Set interrupt priorities
  // DMA 0 and 1 as well as SIO_IRQ_PROC0 are set to PRIO 1
  irq_set_priority (DMA_IRQ_0, 0x40);
  irq_set_priority (DMA_IRQ_1, 0x40);
  irq_set_priority (SIO_IRQ_PROC0, 0x40);

  // Init "special" device, which encapsulates the pico stdio (via USB or UART)
  init_stdio_dev ();
  printf ("stdio dev initialized\n");

  // Initialize PS/2 keyboard driver
  init_ps2key ();
  printf ("ps2 dev initialized\n");

  // Initialize CAS interface
  init_cas ();
  printf ("CAS dev initialized\n");

  // Initialize graphics output first
  init_gdp ();
  printf ("gdp dev initialized\n");

  // Setup simdev struct
  memset (&simdev[0], 0, sizeof (iodev_list) * 16);
  //  simdev[15].iodev_funct = ser_putc;
  simdev[12].queue = cas_queue;
  simdev[7].queue = gdp_queue;
  simdev[6].queue = gdp_page_queue;

  // Clear Fifo
  uint32_t fifo_pop;
  while (multicore_fifo_pop_timeout_us(20,&fifo_pop))
	 printf ("Fifo %08x\n", fifo_pop);

  // Setup FIFO for receiving events from the core handling
  // the Z80 IO ports
  irq_set_exclusive_handler(SIO_IRQ_PROC0, fifo_irq_handler);
  irq_set_enabled(SIO_IRQ_PROC0, true);

  init_par_bus ();
  printf ("par bus initialized\n");

  // Z80 Emulator
  //multicore_launch_core1(z80_emulator);

  // The second core waits until it receives some message over the FIFO
  multicore_fifo_push_blocking((uint32_t) 0);

  reset_z80 ();

  // Now do the event loop
  int bTerm = 0;
  int renew = 1;
  while (true) {
    if (renew)
      {
	printf ("X - XModem receive\n");
	printf ("S - XModem send\n");
	printf ("D - Dump XModem buffer\n");
	printf ("T - Terminal mode\n");
	printf ("I - Dump IO buffer\n");
	printf ("C - Reset CAS bufptr\n");
	//	printf ("S - Start CAS output\n");
	printf ("R - Reset Z80\n\n");
	renew = 0;
      }

    uint8_t ch;
    if (xQueueReceive (stdio_dev.input_queue, &ch, (TickType_t) 10))
      {
	if (bTerm)
	  {
	    if (ch == 27)
	      {
		printf ("Terminal Mode Exit\n");
		bTerm = 0;
	      }
	    else
	      {
		write_io_reg (0x68, ch);
	      }
	  }
	else
	  {
	    switch (ch)
	      {
	      case 'x' :
	      case 'X' : xmodem_receive ();
		break;
	      case 's' :
	      case 'S' : xmodem_send ();
		break;
	      case 'd' :
	      case 'D' : dump_xmod_buffer ();
		break;
	      case 'i' :
	      case 'I' : dump_mem_area ();
		break;
	      case 't' :
	      case 'T' :
		printf ("Entering Terminal Mode\n");
		bTerm = 1;
		break;
	      case 'c' :
	      case 'C' :
		// Reset pointer to xmodem buffer
		// Indicate character available to CAS interface
		xmod_len = 0;
		break;
	      case 'r' :
	      case 'R' : reset_z80 ();
		break;
	      }
	    renew = 1;
	  }
      }

    // Temporary fix for PS/2 Keyboard
    if (xQueueReceive (ps2_dev.input_queue, &ch, (TickType_t) 0))
	{
	  write_io_reg (0x68, ch);
	}
  }
}

/****************************************************************************
 * Name: main
 *
 * Description:
 *   Some initializations of the pico and creation of main task.
 *
 * Input Parameters:
 *   None
 *
 * Returned Value:
 *   None
 *
 ****************************************************************************/

int main() {
  // 160 MHz
  //set_sys_clock_khz(160000, true);

  // 148.5 MHz for 1080p @ 60 Hz
  set_sys_clock_khz(148500, true);
  // TODO: look for implications regarding the FreeRTOS Timing

  // Initialize Serial In- and Output
  stdio_init_all ();
  sleep_ms(200);

  // Task to setup devices and to monitor user inputs through stdio
  BaseType_t monitor_status = xTaskCreate(task_monitor,
					  "MONITOR_TASK",
					  1024,
					  NULL,
					  1,
					  &monitor_task_handle);

  // Start the FreeRTOS scheduler
  if (monitor_status == pdPASS) {
    vTaskStartScheduler();
  }

  // We should never get here, but just in case...
  while(true) {
    // NOP
  };
}

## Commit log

2024-10-05 Added hardware files for BUS backplane, a rebuild of the SBC2 single board computer and the essence of this project the GDPico64 card. Added a few changes in the software.
    [BUS_Rebuild-B_Cu.gbr, BUS_Rebuild-B_Mask.gbr, BUS_Rebuild-B_Paste.gbr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]
2024-10-25 Changed code to only selectively put data on the bus when an emulated device is addressed in the IO space.

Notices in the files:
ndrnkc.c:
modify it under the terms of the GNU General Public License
